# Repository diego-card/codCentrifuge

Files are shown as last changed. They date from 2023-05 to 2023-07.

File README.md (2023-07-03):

# Projeto Centrifuga Inteligente
Arduino codes for the on going Inteligent Centrifuge project.
<br/> <br/>
Projeto final desenvolvido na matéria de TCC no curso de Tecnologia em Sistemas para Internet (2023)
<br/><br/>
Autores: Diego Cardoso e Érika Silva
<br/><br/>
🌱 Projeto desenvolvido para uso em laboratório e sala de aula<br/>
🏫 Professor Orientador: Caio Daoud<br/>
💥 Linguagens utilizadas:<br/>
-C++ <br/>
-Python 3.9<br/>
💥 Tecnologias utilizadas:<br/>
Foram utilizadas no projeto em questão as seguintes tecnologias: Arduino,
impressora 3D e impressora CNC.

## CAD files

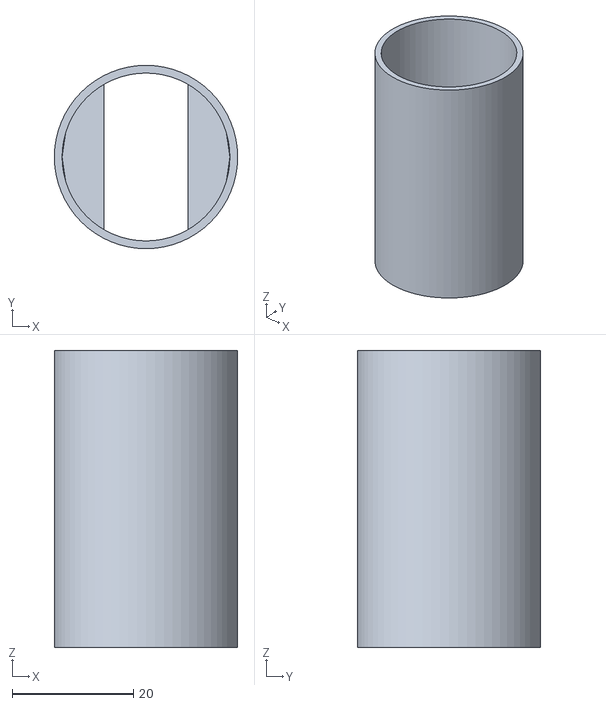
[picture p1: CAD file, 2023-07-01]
Componentes/SuporteRotor.stl
30.2 x 30.2 x 49.0

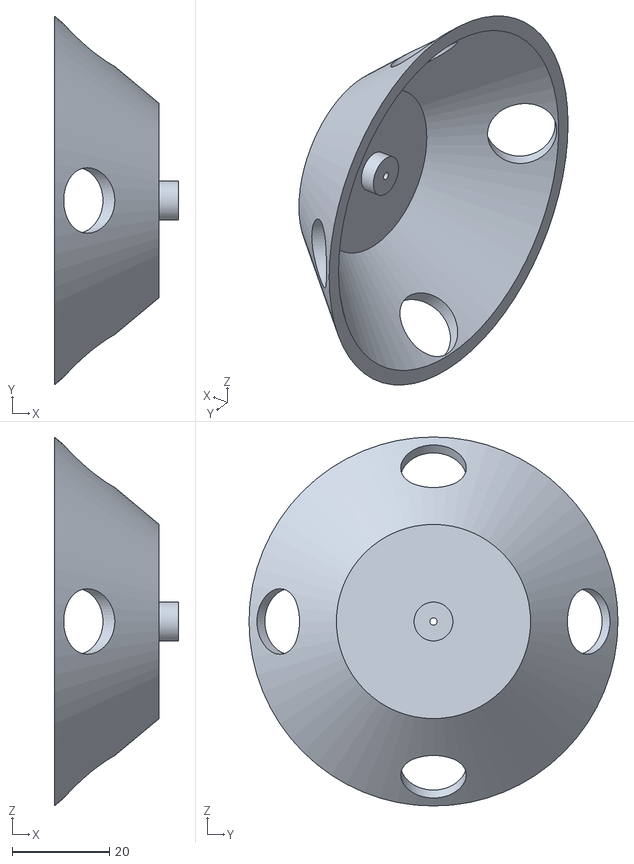
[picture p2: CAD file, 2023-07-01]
Componentes/RotorCentrifuga.stl
25.6 x 76.0 x 76.0

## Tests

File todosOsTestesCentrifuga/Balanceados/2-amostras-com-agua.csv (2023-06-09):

Time | X-axis | Y-axis | Z-axis | Temperature
00:00:00 | 132.0 | 122.0 | 5.0 | 25.0
00:00:02 | 133.0 | 122.0 | 5.0 | 25.0
00:00:03 | 133.0 | 122.0 | 5.0 | 25.0
00:00:03 | 133.0 | 122.0 | 6.0 | 25.0
00:00:03 | 134.0 | 122.0 | 4.0 | 25.0
00:00:03 | 133.0 | 122.0 | 4.0 | 25.0
00:00:03 | 133.0 | 122.0 | 5.0 | 25.0
00:00:04 | 134.0 | 123.0 | 4.0 | 25.0
00:00:04 | 131.0 | 120.0 | 7.0 | 25.0
00:00:04 | 132.0 | 122.0 | 5.0 | 25.0
00:00:04 | 134.0 | 120.0 | 5.0 | 25.0
00:00:04 | 132.0 | 120.0 | 4.0 | 25.0
00:00:04 | 132.0 | 122.0 | 3.0 | 25.0
00:00:05 | 129.0 | 122.0 | 7.0 | 25.0
00:00:05 | 134.0 | 120.0 | 5.0 | 25.0
00:00:05 | 135.0 | 120.0 | 3.0 | 25.0
00:00:05 | 132.0 | 122.0 | 4.0 | 25.0
00:00:06 | 132.0 | 119.0 | 5.0 | 25.0
00:00:06 | 133.0 | 121.0 | 5.0 | 25.0
00:00:06 | 134.0 | 121.0 | 4.0 | 25.0
00:00:06 | 133.0 | 120.0 | 4.0 | 25.0
00:00:06 | 142.0 | 122.0 | 13.0 | 25.0
00:00:07 | 132.0 | 120.0 | 7.0 | 25.0
00:00:07 | 133.0 | 120.0 | 6.0 | 25.0
00:00:07 | 136.0 | 123.0 | 2.0 | 25.0
00:00:07 | 134.0 | 125.0 | 2.0 | 25.0
00:00:07 | 135.0 | 121.0 | 4.0 | 25.0
00:00:08 | 133.0 | 123.0 | 5.0 | 25.0
00:00:08 | 134.0 | 122.0 | 4.0 | 25.0
00:00:08 | 135.0 | 122.0 | 2.0 | 25.0
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

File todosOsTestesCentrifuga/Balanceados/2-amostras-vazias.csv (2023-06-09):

Time | X-axis | Y-axis | Z-axis | Temperature
00:00:00 | 129.0 | 120.0 | 4.0 | 26.0
00:00:02 | 132.0 | 120.0 | 4.0 | 26.0
00:00:03 | 130.0 | 119.0 | 4.0 | 26.0
00:00:03 | 134.0 | 119.0 | 5.0 | 26.0
00:00:03 | 130.0 | 120.0 | 5.0 | 26.0
00:00:03 | 133.0 | 118.0 | 4.0 | 26.0
00:00:03 | 129.0 | 117.0 | 5.0 | 26.0
00:00:04 | 133.0 | 118.0 | 3.0 | 26.0
00:00:04 | 131.0 | 120.0 | 4.0 | 26.0
00:00:04 | 132.0 | 120.0 | 4.0 | 26.0
00:00:04 | 133.0 | 116.0 | 4.0 | 26.0
00:00:04 | 131.0 | 119.0 | 4.0 | 26.0
00:00:05 | 131.0 | 117.0 | 5.0 | 26.0
00:00:05 | 131.0 | 120.0 | 5.0 | 26.0
00:00:05 | 130.0 | 119.0 | 4.0 | 26.0
00:00:05 | 132.0 | 119.0 | 2.0 | 26.0
00:00:05 | 131.0 | 118.0 | 6.0 | 26.0
00:00:06 | 133.0 | 118.0 | 5.0 | 26.0
00:00:06 | 131.0 | 118.0 | 3.0 | 26.0
00:00:06 | 131.0 | 119.0 | 4.0 | 26.0
00:00:06 | 133.0 | 120.0 | 5.0 | 26.0
00:00:06 | 131.0 | 118.0 | 4.0 | 26.0
00:00:07 | 133.0 | 118.0 | 3.0 | 26.0
00:00:07 | 134.0 | 119.0 | 5.0 | 26.0
00:00:07 | 128.0 | 120.0 | 4.0 | 26.0
00:00:07 | 132.0 | 119.0 | 4.0 | 26.0
00:00:07 | 130.0 | 119.0 | 4.0 | 26.0
00:00:08 | 131.0 | 119.0 | 4.0 | 26.0
00:00:08 | 131.0 | 119.0 | 5.0 | 26.0
00:00:08 | 131.0 | 118.0 | 4.0 | 26.0
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

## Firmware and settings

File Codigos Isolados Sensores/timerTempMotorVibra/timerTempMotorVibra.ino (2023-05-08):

#include <Thermistor.h>
Thermistor temp(0); //VARIÁVEL DO TIPO THERMISTOR, INDICANDO O PINO ANALÓGICO (A2) EM QUE O SENSOR ESTÁ CONECTADO
// Include Wire Library for I2C
#include <Wire.h>

#define VIBRATION_SAMPLE_ARRAY_SIZE 100
// if we 5 or more vibration events over a five second period then a vibration alarm is triggered
#define VIBRATION_EVENTS_ALARM_THRESHOLD_COUNT 5
#define VIBRATION_EVENTS_ALARM_THRESHOLD_PERIOD_MILLIS 5000

unsigned long previousMillis = 0; // variable to store the time of the last analog read
const long interval = 20; // interval at which to read the analog value

long vibrationEvents[VIBRATION_SAMPLE_ARRAY_SIZE];
int vibrationEventIndex;

// hbridge
#include <MX1508.h>

#define PINA 9
#define PINB 10
#define NUMPWM 2

MX1508 motorA(PINA,PINB, FAST_DECAY, NUMPWM);

// Include Adafruit Graphics & OLED libraries
#include <Adafruit_GFX.h>
#include <Adafruit_SSD1306.h>
#include <Fonts/FreeMonoBold9pt7b.h>

// Reset pin not used but needed for library
#define OLED_RESET 12
Adafruit_SSD1306 display(OLED_RESET);

#include "Countimer.h"
Countimer tdown;
#include <EEPROM.h>                   // Include the EEPROM library for reading and writing to non-volatile memory

#define bt_select 4                  // Define the pin number for the select button
#define bt_mode 3                    // Define the pin number for the mode button
#define bt_up 2                      // Define the pin number for the up button

int time_s = 0;
int time_m = 0;
int time_h = 0;

int set = 0;
int flag1 = 0, flag2 = 0;

int relay = 5;

bool running = false;

void setup() {
  EEPROM.write(1, 0);
  EEPROM.write(2, 0);
  EEPROM.write(3, 0);

  Wire.begin();
  display.begin(SSD1306_SWITCHCAPVCC, 0x3C);
  Serial.begin(9600);

  pinMode(bt_mode, INPUT_PULLUP);
  pinMode(bt_up, INPUT_PULLUP);
  pinMode(bt_select, INPUT_PULLUP);
  pinMode(relay, OUTPUT);
  pinMode(LED_BUILTIN, OUTPUT);
  
  vibrationEventIndex = 0;
  clearVibrationEvents();
  // Necessary for the display
  display.setTextColor(WHITE);

  display.clearDisplay();
  // display.setCursor(0, 0);
  // display.print("Countdown  Timer");
  // Set the timer interval to 999 milliseconds and assign the print_time function as the callback function
  tdown.setInterval(print_time, 999);
  eeprom_read();
  delay(1000);
  display.display();
}

void print_time() {
  time_s = time_s-1;

  if(time_s<0){
    time_s=59; 
    time_m = time_m-1;
  }
  if(time_m<0){
    time_m=59;
    time_h = time_h-1;
  }
}

void tdownComplete() {
  motorA.stopMotor();
  Serial.print("ok");
}

//tdown.stop();
bool perigoTemp = false;
bool perigoVibra = false;

void loop() {
  //Serial.println(analogRead(A3));
  //Vibration detection
  if(analogRead(A3) >= 1){
    long currentMillis = millis();
    addVibrationSample(currentMillis);
    if(isVibrationAlarmTiggered()){
      triggerAlarm();
      Serial.println(String(millis()) + "\t ALARM");
    }
    delay(100); // wait for current vibration shock to subside
  }
  
  //motor variables
  static unsigned long lastMilli = 0;
  static bool cwDirection = true; // assume initial direction(positive pwm) is clockwise
  static int pwm = 1;

  tdown.run();

  int temperature = temp.getTemp();
  // Serial.print(temperature);
  if(temperature > 40){
    motorA.stopMotor();
    display.clearDisplay();
    display.setFont(NULL);
    display.setTextSize(1);
    display.setCursor(0, 0);
    display.print("DESLIGUE A CENTRIFUGA");
    display.setTextSize(2);
    display.setCursor(0, 10);
    display.print("QUENTE:");
    display.setCursor(90, 10);
    display.print(temperature);
    display.setCursor(115, 10);
    display.print("C");
    Serial.print("Danger!");
    perigoTemp = true;
  } else {
    perigoTemp = false;
  }

  //only enter if both perigo are false
  if(perigoTemp == false && perigoVibra == false){
    if (digitalRead(bt_mode) == 0) {
      if (flag1 == 0 && flag2 == 0) {
        flag1 = 1;
        set = set + 1;
        if (set > 3) { set = 0; }
        delay(100);
      }
    } else {
      flag1 = 0;
    }

    if (digitalRead(bt_up) == 0) {
      if (set == 0) {
        tdown.start();
        flag2 = 1;
      }
      if (set == 1) { time_s++; }
      if (set == 2) { time_m++; }
      if (set == 3) { time_h++; }
      if (time_s > 59) { time_s = 0; }
      if (time_m > 59) { time_m = 0; }
      if (time_h > 99) { time_h = 0; }
      if (set > 0) { eeprom_write(); }
      delay(25);
    }

    // if (digitalRead(bt_down) == 0) {
    //   if (set == 0) {
    //     tdown.stop();
    //     flag2 = 0;
    //   }
    //   if (set == 1) { time_s--; }
    //   if (set == 2) { time_m--; }
    //   if (set == 3) { time_h--; }
    //   if (time_s < 0) { time_s = 59; }
    //   if (time_m < 0) { time_m = 59; }
    //   if (time_h < 0) { time_h = 99; }
    //   if (set > 0) { eeprom_write(); }
    //   delay(200);
    // }

    if (digitalRead(bt_select) == 0) {
      // flag2 = 1;
      // eeprom_read();
      // digitalWrite(relay, HIGH);
      // tdown.restart();
      // tdown.start();
      
      if(running == false) {
        flag2 = 1;  
        // eeprom_read();
        // digitalWrite(relay, HIGH);
        tdown.start();

        motorA.motorGo(100);

        running = !running;
      } else {
        // flag2 = 1;  
        // eeprom_read();
        // digitalWrite(relay, LOW);
        tdown.pause();
        
        motorA.stopMotor();

        running = !running;
      }
    }

    // display.fillRect(0, 10, 128, 8, BLACK);

    if (set == 0) {
      display.clearDisplay();
      display.setFont(NULL); //Reseting font
      display.setTextSize(1);
      display.setCursor(0, 0);
      display.print("Temperatura:");
      display.setCursor(80, 0);
      display.print(temperature);
      display.print("C");
      display.setCursor(0, 10);
      display.print("Aperte para mudar");
    }
    if (set == 1) {
      display.clearDisplay();
      display.setFont(NULL);
      display.setTextSize(1);
      display.setCursor(0, 0);
      display.print("Temperatura:");
      display.setCursor(80, 0);
      display.print(temperature);
      display.print("C");
      display.setCursor(0, 10);
      display.print("Definir Segundos");
    }
    if (set == 2) {
      display.clearDisplay();
      display.setFont(NULL);
      display.setTextSize(1);
      display.setCursor(0, 0);
      display.print("Temperatura:");
      display.setCursor(80, 0);
      display.print(temperature);
      display.print("C");
      display.setCursor(0, 10); 
      display.print("Definir Minutos"); 
    }
    if (set == 3) {
      display.clearDisplay();
      display.setFont(NULL);
      display.setTextSize(1);
      display.setCursor(0, 0);
      display.print("Temperatura:");
      display.setCursor(80, 0);
      display.print(temperature);
      display.print("C");
      display.setCursor(0, 10);
      display.print("Definir Horas");
    }

    display.setCursor(20, 25);
    display.setFont(&FreeMonoBold9pt7b);
    if (time_h <= 9) { display.print("0"); }
    display.print(time_h);
    display.print(":");
    if (time_m <= 9) { display.print("0"); }
    display.print(time_m);
    display.print(":");
    if (time_s <= 9) { display.print("0"); }
    display.print(time_s);
    display.print("   ");

    if (time_s == 0 && time_m == 0 && time_h == 0 && flag2 == 1) {
      flag2 = 0;
      tdown.stop();
      digitalWrite(relay, LOW);
      tdownComplete();
    }

    if (flag2 == 1) {
      digitalWrite(relay, HIGH);
    } else {
      digitalWrite(relay, LOW);
    }
  }

  delay(1);
  display.display();
}

void eeprom_write() {
  EEPROM.write(1, time_s);
  EEPROM.write(2, time_m);
  EEPROM.write(3, time_h);
}

void eeprom_read() {
  time_s = EEPROM.read(1);
  time_m = EEPROM.read(2);
  time_h = EEPROM.read(3);
}
// Vibração
void addVibrationSample(long vibrationMillis){
   vibrationEvents[vibrationEventIndex++] = vibrationMillis;
   if(vibrationEventIndex >= VIBRATION_SAMPLE_ARRAY_SIZE){
     vibrationEventIndex = 0; // wrap vibration sample index around when we get to end of sample array
   }
}

boolean triggerAlarm(){
  tdownComplete();
  perigoVibra = true;

  display.clearDisplay();
  display.setFont(NULL);
  display.setCursor(0, 0);
  display.print("DESLIGUE A CENTRIFUGA");
  display.setCursor(0, 10);
  display.print("VIBRANDO MUITO");

  //digitalWrite(VIBRATION_SENSOR_DIGITAL_OUTPUT_PIN, HIGH);
  digitalWrite(LED_BUILTIN, HIGH);
  delay(1000);
  //digitalWrite(VIBRATION_SENSOR_DIGITAL_OUTPUT_PIN, LOW);
  digitalWrite(LED_BUILTIN, LOW);
  clearVibrationEvents();
}

void clearVibrationEvents(){
  for(int i = 0; i < VIBRATION_SAMPLE_ARRAY_SIZE ; ++i){
    vibrationEvents[i] = -1;
  }
}

boolean isVibrationAlarmTiggered(){
  long thresholdMillis = millis() - VIBRATION_EVENTS_ALARM_THRESHOLD_PERIOD_MILLIS;
  if(thresholdMillis < 0) thresholdMillis = 0;
  int numVibrationsSinceThreshold = 0;
  for(int i = 0; i < VIBRATION_SAMPLE_ARRAY_SIZE ; ++i){
    if(vibrationEvents[i] >= thresholdMillis){
      ++numVibrationsSinceThreshold;
    }
  }
  
  Serial.println(String(millis()) + "\t# events: " + String(numVibrationsSinceThreshold));
  boolean alarmTriggered = false;
  if(numVibrationsSinceThreshold >= VIBRATION_EVENTS_ALARM_THRESHOLD_COUNT){
    alarmTriggered = true;
  }
  
  return alarmTriggered;
}

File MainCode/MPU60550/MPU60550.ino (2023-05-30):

#include "Wire.h"       
#include "I2Cdev.h"     
#include "MPU6050.h"    

MPU6050 mpu;
int16_t ax, ay, az;
int16_t gx, gy, gz;

struct MyData {
  byte X;
  byte Y;
  byte Z;
};

MyData data;

void setup()
{
  Serial.begin(9600);
  Wire.begin();
  mpu.initialize();
  pinMode(LED_BUILTIN, OUTPUT);
}

void loop()
{
  mpu.getMotion6(&ax, &ay, &az, &gx, &gy, &gz);
  data.X = map(ax, -17000, 17000, 0, 255 ); // X axis data
  data.Y = map(ay, -17000, 17000, 0, 255); 
  data.Z = map(az, -17000, 17000, 0, 255);  // Y axis data
  delay(150);
  //Serial.print("Axis X = ");
  Serial.print(data.X);
  Serial.print(",");
  //Serial.print("Axis Y = ");
  Serial.print(data.Y);
  Serial.print(",");
  //Serial.print("Axis Z  = ");
  Serial.println(data.Z);

  if(data.Z <= 20){
    digitalWrite(LED_BUILTIN, HIGH);
  } else {
    digitalWrite(LED_BUILTIN, LOW);
  }
}

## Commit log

2022-12-03 Adicionado navegação com motor
2023-02-23 Temperature and changing menu
2023-03-30 Starting new timer for the centrifuge
2023-04-03 temperatura e novo timer
2023-04-04 Timer novo com motor e temperatura
2023-05-01 new vibration detection and modified temperatura and newtimer
    [newTimerMotorTemp.ino, temperatura.ino, vibrationDetection.ino]
2023-05-08 modified vibrationDetection and added timerTempMotorVibra
    [timerTempMotorVibra.ino, vibrationDetection.ino]
2023-05-30 Novo sensor de vibração: MPU-6050
2023-06-09 Adicionando todos os testes realizados.
    [1-amostra-vazia.csv, 2-amostra-agua-e-vazio.csv, 2-amostra-vazio-lado-errado.csv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]
2023-06-14 modificando resultados e código principal
    [ESTATISTICAS_BALANCEADAS.csv]
2023-06-20 Testes de vibração e temperatura da centrífuga
    [1hTemp.csv, 2-vazio-DPS-de-quente.csv, Temp21minDesbalanceado.csv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]
2023-07-01 Organizando códigos dos sensores e pastas de testes
    [1hTemp.csv, 2-vazio-DPS-de-quente.csv, RotorCentrifuga.stl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]
